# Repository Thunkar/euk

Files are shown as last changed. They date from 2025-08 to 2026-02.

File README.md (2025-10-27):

# EUK Split Keyboard

A split ergonomic keyboard project with customizable accessories and per-key RGB lighting.

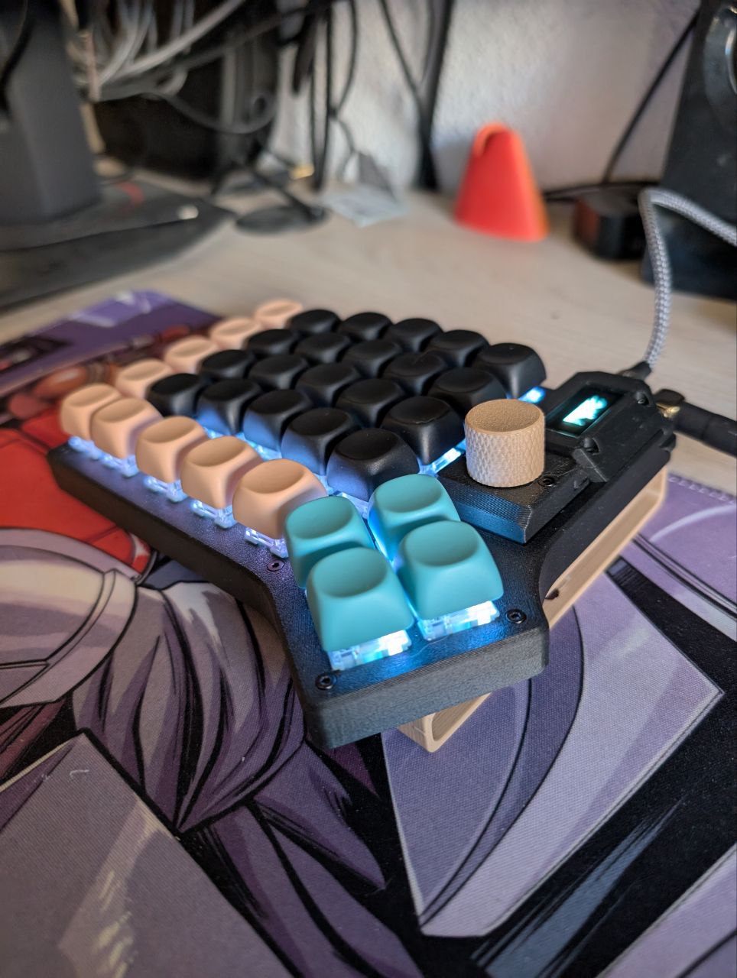
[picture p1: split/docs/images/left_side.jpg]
Left side

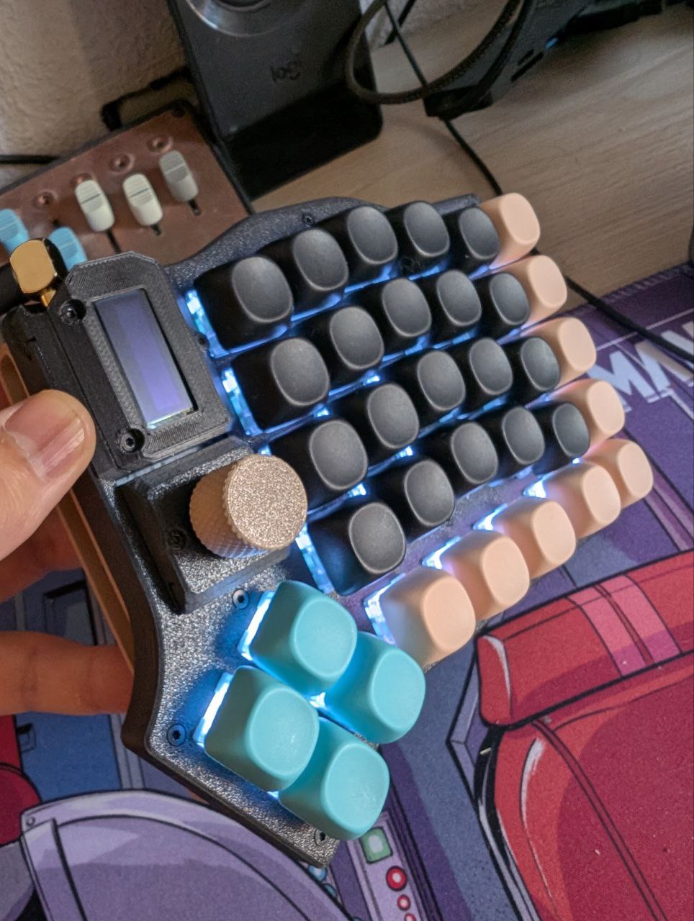
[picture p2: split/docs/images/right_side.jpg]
Right side

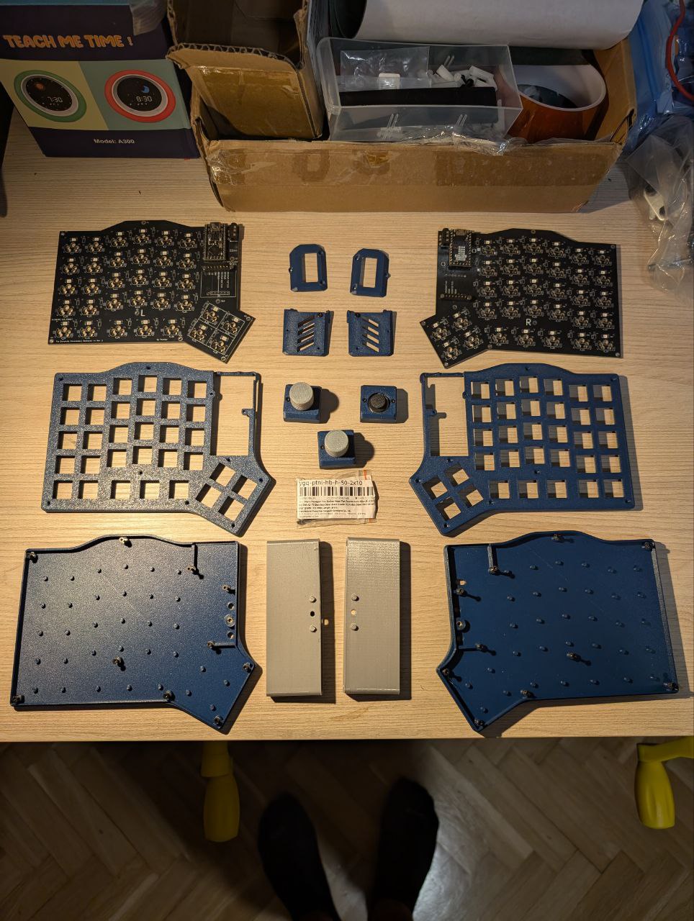
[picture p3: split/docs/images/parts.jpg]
Parts


## Features

- Split design for ergonomic typing
- Hot-swappable MX switches
- Per-key RGB lighting (SK6812 mini-e LEDs)
- RP2040-based controller
- Optional accessories:
  - OLED screen
  - Rotary encoder
  - Analog joystick
  - Potentiometer
  - Tenting support

## Documentation

- [Bill of Materials (BOM)](./split/docs/BOM.md) - Complete list of components needed
- [Ordering PCBs](./split/docs/ORDERING_PCBS.md) - Guide for ordering the printed circuit boards
- [Assembly Guide](./split/docs/ASSEMBLY.md) - Step-by-step assembly instructions

## Project Structure

- `cad/` - 3D printable case and accessory files
- `pcb/` - KiCad PCB design files
- `docs/` - Documentation and guides
- `via.layout.json` - VIA keyboard configurator layout
- `via.definition.json` - VIA keyboard definition
- `kle.definition.json` - https://keyboard-layout-editor.com/ definition

## Getting Started

1. Review the [BOM](docs/BOM.md) to buy all required components
2. Follow the [PCB ordering guide](docs/ORDERING_PCBS.md) and get yourself some boards
3. Print the required parts from the `cad/` directory
4. Follow the [assembly guide](docs/ASSEMBLY.md) to build it!

## Firmware

This keyboard uses QMK/VIA firmware. Use the included `via.layout.json` file to configure your keyboard layout in [VIA](https://usevia.app/).

At the moment, use the QMK fork at https://github.com/Thunkar/qmk_firmware

After installation, flash with:

`qmk flash -kb euk/split -km default`

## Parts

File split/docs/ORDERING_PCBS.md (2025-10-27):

# JLCPCB

To keep manufacturing costs low, there's actually a single PCB in this project. Flip it around, you have the other hand! It follows that you at least need 2 PCBs to to assemble a single keyboard.

This project was created around JLCPCB's PCB assembly service. In the end, no SMD components are assembled from the factory, so any other PCB manufacturing service will do.

To order, just upload the production files under `pcb/jlcpcb/production_files` (GERBER .zip and BOM/CPL files). Keep ALL options in their default settings, except for the PCB color which can be selected according to taste (or lack thereof).

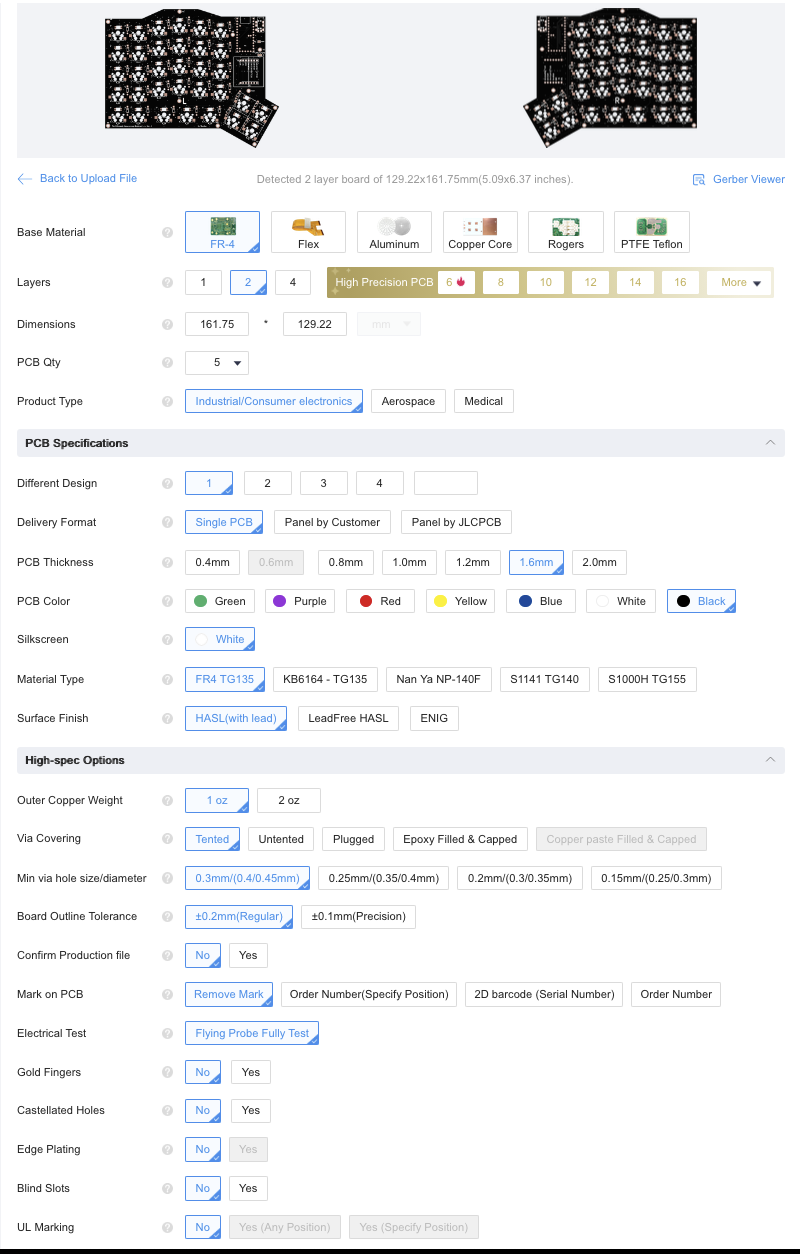
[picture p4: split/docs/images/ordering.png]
default settings


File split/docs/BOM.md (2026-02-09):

# BOM

## Hardware (per side)

| Item | Quantity | Link |
| --- | --- | --- |
| M2x10mm countersunk screw | 8 | https://es.aliexpress.com/item/1005006468976904.html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 |
| M2x14mm countersunk screw | 2 | https://es.aliexpress.com/item/1005006468976904.html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 |
| M2x4mm countersunk screw | 1 | https://es.aliexpress.com/item/1005006468976904.html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 |
| M3x6mm countersunk screw | 1 | https://es.aliexpress.com/item/1005006468976904.html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 |
| M2x4x3.2mm brass inserts | 10 | https://es.aliexpress.com/item/1005006472702418.html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 |
| M2x3x3.2mm brass inserts | 1 | https://es.aliexpress.com/item/1005006472702418.html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 |
| M3x6x4.5mm brass inserts | 1 | https://es.aliexpress.com/item/1005006472702418.html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 |
| TRRS jack female | 1 | https://es.aliexpress.com/item/33029465106.html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 |
| RP2040 pro micro | 1 | https://es.aliexpress.com/item/1005006599393967.html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 |
| 7 pin POGO connectors | 1 pair | https://es.aliexpress.com/item/1005005284441979.html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 |
| Hot swappable MX sockets (1511) | 33 | https://es.aliexpress.com/item/1005007639688349.html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,scm-url:1007.40050.354490.0,pvid:6b06f592-2422-491c-a082-58f7d255a081,tpp_buckets:668%232846%238115%232000&pdp_ext_f=%7B%22order%22%3A%2225%22%2C%22eval%22%3A%221%22%2C%22sceneId%22%3A%2230050%22%2C%22fromPage%22%3A%22recommend%22%7D&pdp_npi=6%40dis%21EUR%213.43%213.09%21%21%2127.71%2124.96%21%40211b80c217614877862336159e153c%2112000041605806626%21rec%21ES%21137979760%21XZ%211%210%21n_tag%3A-29919%3Bd%3A60ba6b69%3Bm03_new_user%3A-29895&utparam-url=scene%3ApcDetailBottomMoreOtherSeller%7Cquery_from%3A%7Cx_object_id%3A1005007639688349%7C_p_origin_prod%3A |
| SK6812 mini-e LEDs | 33 | https://es.aliexpress.com/item/1005007863635868.html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 |
| 1N4148 DO-35 diode | 33 | https://es.aliexpress.com/item/1005009372401863.html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 |
| OLED screen | 1 | https://es.aliexpress.com/item/1005008640132638.html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 |

## Misc hardware

| Item | Quantity | Link |
| --- | --- | --- |
| TRRS cable | 1 | https://es.aliexpress.com/item/1005005658637420.html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 |

## Optional

| Item | Quantity | Link |
| --- | --- | --- |
| EC11 encoder (short stem) | 1 | https://es.aliexpress.com/item/1005003569104746.html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,scm-url:1007.40050.354490.0,pvid:5a6a783c-6c5c-47c6-a442-9901f6537dc1,tpp_buckets:668%232846%238115%232000&pdp_ext_f=%7B%22order%22%3A%228%22%2C%22eval%22%3A%221%22%2C%22sceneId%22%3A%2230050%22%2C%22fromPage%22%3A%22recommend%22%7D&pdp_npi=6%40dis%21EUR%210.76%210.63%21%21%210.86%210.71%21%40211b6c1917614890539918085e8606%2112000051081200717%21rec%21ES%21137979760%21XZ%211%210%21n_tag%3A-29919%3Bd%3A60ba6b69%3Bm03_new_user%3A-29895&utparam-url=scene%3ApcDetailTopMoreOtherSeller%7Cquery_from%3A%7Cx_object_id%3A1005003569104746%7C_p_origin_prod%3A |
| Joystick | 1 | https://es.aliexpress.com/item/1005006734905352.html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 |
| RK097N potentiometer | 1 | https://www.aliexpress.com/item/1005009223196391.html?spm=a2g0o.order_list.order_list_main.177.404c194dESBhOC |

# Printed parts

## Per side

| Part | Quantity |
|---|---|
| splitBase.stl | 1 |
| splitTop.stl | 1 |
| mcuCover.stl | 1 |
| screenHolder.stl | 1 |

## Accessories

### Tenting

| Part | Quantity |
|---|---|
| tent.stl | 1 |

### Encoder

| Part | Quantity |
|---|---|
| encoderEnclosureBase.stl | 1 |
| encoderEnclosureMid.stl | 1 |
| encoderEnclosureTop.stl | 1 |
| pad.stl | 1 |

### Potentiometer

| Part | Quantity |
|---|---|
| potEnclosureBase.stl | 1 |
| potEnclosureMid.stl | 1 |
| potEnclosureTop.stl | 1 |
| pad.stl | 1 |

### Joystick

| Part | Quantity |
|---|---|
| joytstickEnclosureBase.stl | 1 |
| joytstickEnclosureMid.stl | 1 |
| joytstickEnclosureTop.stl | 1 |
| pad.stl | 1 |

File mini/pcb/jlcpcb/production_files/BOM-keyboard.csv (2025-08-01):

Comment | Designator | Footprint | LCSC | Quantity
D | D_0,D_1,D_10,D_11,D_12,D_13,D_14,D_15,D_16,D_17,D_18,D_19,D_2,D_20,D_21,D_22,D_23,D_24,D_25,D_26,D_27,D_28,D_29,D_3,D_30,D_31,D_32,D_4,D_5,D_6,D_7,D_8,D_9 | D_SOD-123_Reversible | C8598 | 33
KEYSW | K_5 | Kailh_socket_MX_reversible |  | 1
KEYSW | K_1 | Kailh_socket_MX_reversible |  | 1
KEYSW | K_4 | Kailh_socket_MX_reversible |  | 1
KEYSW | K_32 | Kailh_socket_MX_reversible |  | 1
KEYSW | K_31 | Kailh_socket_MX_reversible |  | 1
KEYSW | K_30 | Kailh_socket_MX_reversible |  | 1
KEYSW | K_29 | Kailh_socket_MX_reversible |  | 1
KEYSW | K_28 | Kailh_socket_MX_reversible |  | 1
KEYSW | K_27 | Kailh_socket_MX_reversible |  | 1
KEYSW | K_26 | Kailh_socket_MX_reversible |  | 1
KEYSW | K_25 | Kailh_socket_MX_reversible |  | 1
KEYSW | K_24 | Kailh_socket_MX_reversible |  | 1
KEYSW | K_23 | Kailh_socket_MX_reversible |  | 1
KEYSW | K_22 | Kailh_socket_MX_reversible |  | 1
KEYSW | K_21 | Kailh_socket_MX_reversible |  | 1
KEYSW | K_20 | Kailh_socket_MX_reversible |  | 1
KEYSW | K_19 | Kailh_socket_MX_reversible |  | 1
KEYSW | K_18 | Kailh_socket_MX_reversible |  | 1
KEYSW | K_17 | Kailh_socket_MX_reversible |  | 1
KEYSW | K_16 | Kailh_socket_MX_reversible |  | 1
KEYSW | K_15 | Kailh_socket_MX_reversible |  | 1
KEYSW | K_14 | Kailh_socket_MX_reversible |  | 1
KEYSW | K_13 | Kailh_socket_MX_reversible |  | 1
KEYSW | K_12 | Kailh_socket_MX_reversible |  | 1
KEYSW | K_11 | Kailh_socket_MX_reversible |  | 1
KEYSW | K_10 | Kailh_socket_MX_reversible |  | 1
KEYSW | K_9 | Kailh_socket_MX_reversible |  | 1
KEYSW | K_8 | Kailh_socket_MX_reversible |  | 1
KEYSW | K_7 | Kailh_socket_MX_reversible |  | 1
KEYSW | K_6 | Kailh_socket_MX_reversible |  | 1
KEYSW | K_3 | Kailh_socket_MX_reversible |  | 1
KEYSW | K_2 | Kailh_socket_MX_reversible |  | 1
KEYSW | K_0 | Kailh_socket_MX_reversible |  | 1
IO | J2 | PinHeader_1x05_P2.54mm_Vertical |  | 1
TRRS | J1 | TRRS_JACK_MJ4PP9 |  | 1
WS2812B | D25 | SK6812-MINI-E |  | 1
WS2812B | D2 | SK6812-MINI-E |  | 1
WS2812B | D27 | SK6812-MINI-E |  | 1
WS2812B | D33 | SK6812-MINI-E |  | 1
WS2812B | D28 | SK6812-MINI-E |  | 1
WS2812B | D32 | SK6812-MINI-E |  | 1
WS2812B | D31 | SK6812-MINI-E |  | 1
WS2812B | D3 | SK6812-MINI-E |  | 1
WS2812B | D12 | SK6812-MINI-E |  | 1
WS2812B | D15 | SK6812-MINI-E |  | 1
WS2812B | D1 | SK6812-MINI-E |  | 1
WS2812B | D16 | SK6812-MINI-E |  | 1
WS2812B | D18 | SK6812-MINI-E |  | 1
WS2812B | D29 | SK6812-MINI-E |  | 1
WS2812B | D13 | SK6812-MINI-E |  | 1
WS2812B | D6 | SK6812-MINI-E |  | 1
WS2812B | D21 | SK6812-MINI-E |  | 1
WS2812B | D4 | SK6812-MINI-E |  | 1
WS2812B | D26 | SK6812-MINI-E |  | 1
WS2812B | D20 | SK6812-MINI-E |  | 1
WS2812B | D17 | SK6812-MINI-E |  | 1
WS2812B | D5 | SK6812-MINI-E |  | 1
WS2812B | D11 | SK6812-MINI-E |  | 1
WS2812B | D30 | SK6812-MINI-E |  | 1
WS2812B | D8 | SK6812-MINI-E |  | 1
WS2812B | D7 | SK6812-MINI-E |  | 1
WS2812B | D10 | SK6812-MINI-E |  | 1
WS2812B | D22 | SK6812-MINI-E |  | 1
WS2812B | D14 | SK6812-MINI-E |  | 1
WS2812B | D9 | SK6812-MINI-E |  | 1
WS2812B | D24 | SK6812-MINI-E |  | 1
WS2812B | D19 | SK6812-MINI-E |  | 1
WS2812B | D23 | SK6812-MINI-E |  | 1
~ | U1 | pro_micro_rp2040 |  | 1

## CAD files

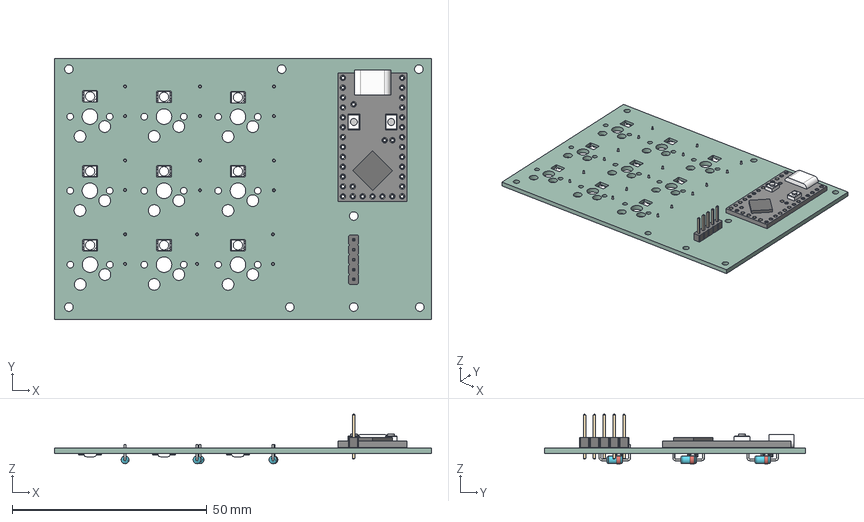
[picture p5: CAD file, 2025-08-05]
mini/pcb/keyboard-mini.step
96.9 x 67.1 x 12.7 mm
Pins x 9
PinHeader_1x05_P2.54mm_Vertical
pro_micro_rp2040
D_DO-35_SOD27_P7.62mm_Horizontal x 9
keyboard-mini_PCB

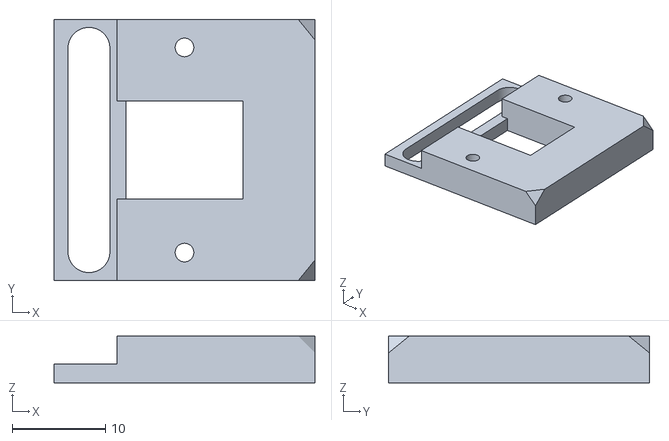
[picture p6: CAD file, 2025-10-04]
split/cad/potEnclosureMid.stl
28.0 x 28.0 x 5.00

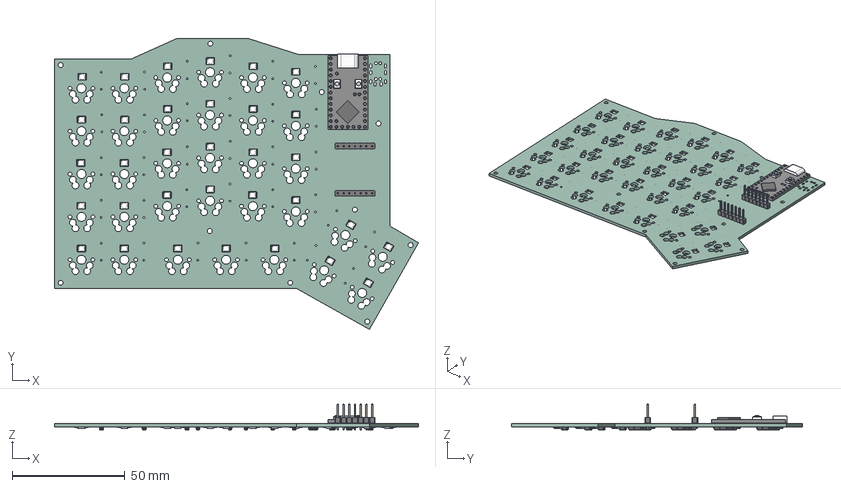
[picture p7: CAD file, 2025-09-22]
split/pcb/rev2.step
161.8 x 129.2 x 11.5 mm
PinHeader_1x07_P2.54mm_Vertical x 2
pro_micro_rp2040
D_SOD-123 x 33
Pins x 33
keyboard_PCB

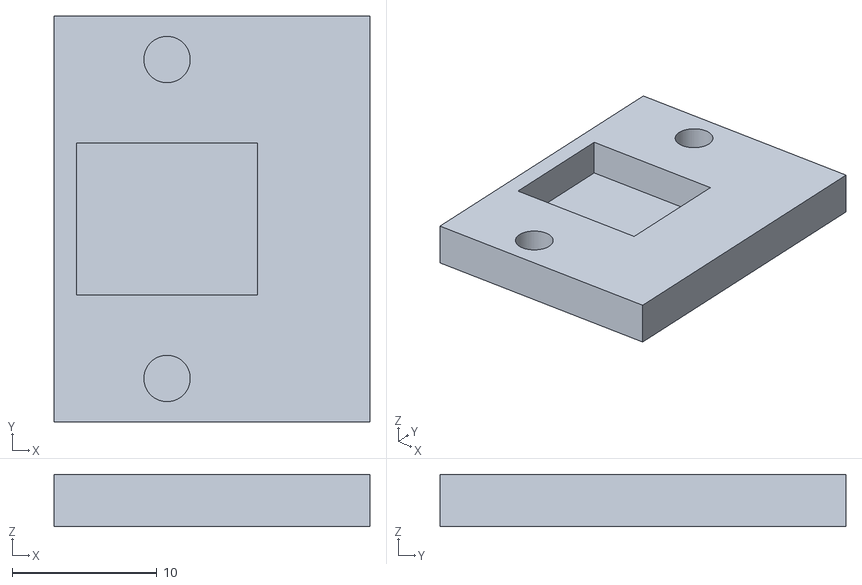
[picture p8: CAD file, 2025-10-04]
split/cad/potEnclosureBase.stl
21.8 x 28.0 x 3.60

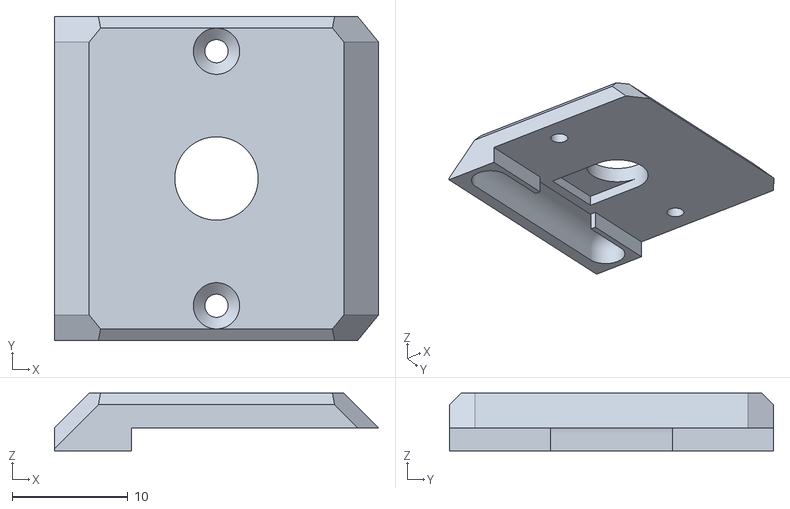
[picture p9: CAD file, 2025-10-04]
split/cad/potEnclosureTop.stl
28.0 x 28.0 x 5.00

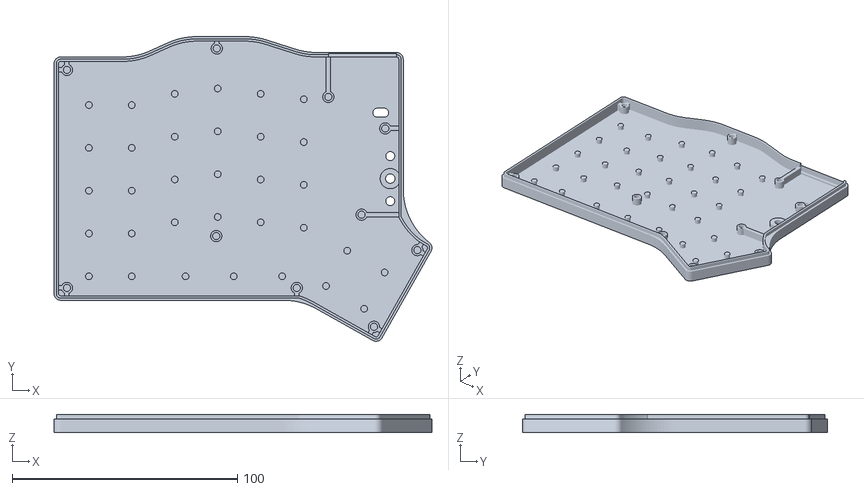
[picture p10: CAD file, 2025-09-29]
split/cad/splitBase.stl
167.7 x 135.2 x 8.00

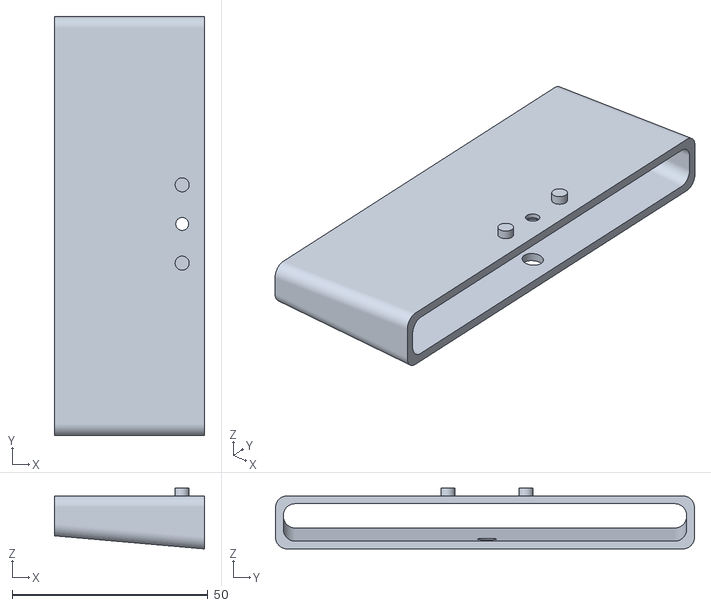
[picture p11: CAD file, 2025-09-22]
split/cad/tent.stl
38.4 x 107.0 x 15.6

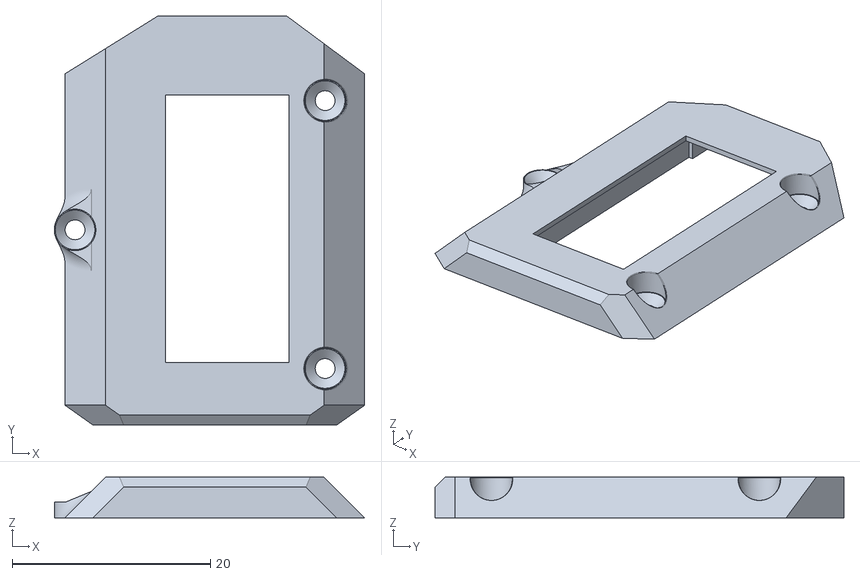
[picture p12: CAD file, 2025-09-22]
split/cad/screenHolder.stl
31.4 x 41.3 x 4.10

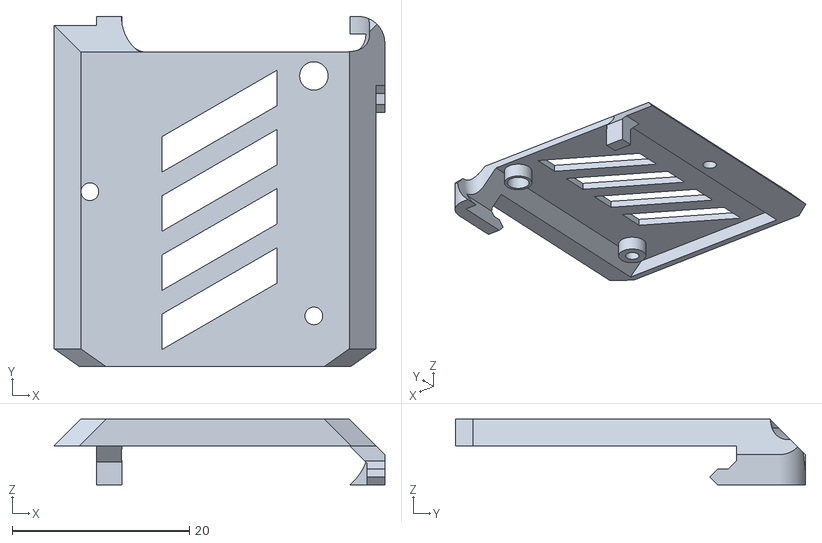
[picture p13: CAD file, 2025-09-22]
split/cad/mcuCover.stl
37.3 x 39.5 x 7.40

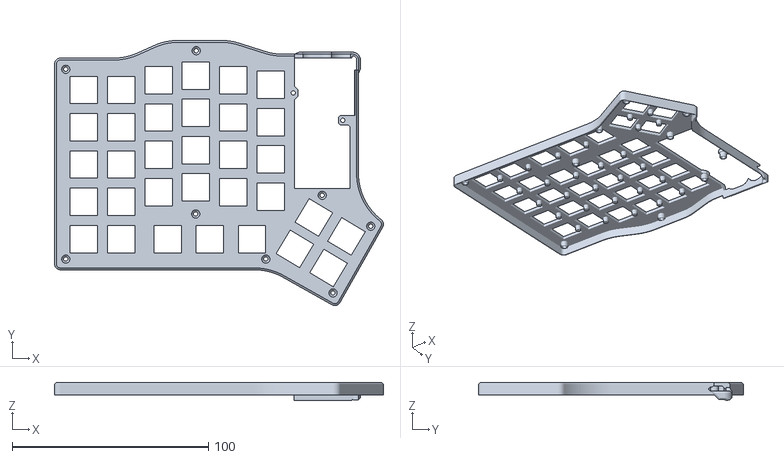
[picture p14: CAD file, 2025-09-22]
split/cad/splitTop.stl
167.7 x 135.2 x 9.40

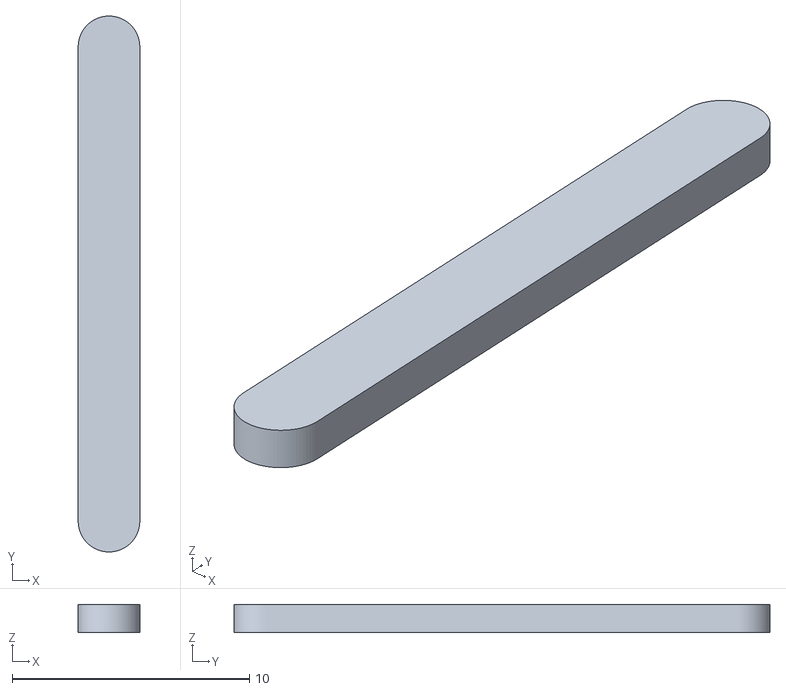
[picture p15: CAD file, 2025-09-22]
split/cad/pad.stl
2.60 x 22.6 x 1.20

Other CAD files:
split/cad/encoderEnclosureMid.stl
split/cad/encoderEnclosureBase.stl
split/cad/encoderEnclosureTop.stl

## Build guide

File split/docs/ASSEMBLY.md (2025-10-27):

# Soldering

Pay close attention to the orientation of components and which side of the PCB you're actually assembling. Most of the soldering for a given side must be done from the OPPOSITE SIDE. Once assembled, everything except for the MCU, TRRS jack and magnetic connector will be the bottom of the board.

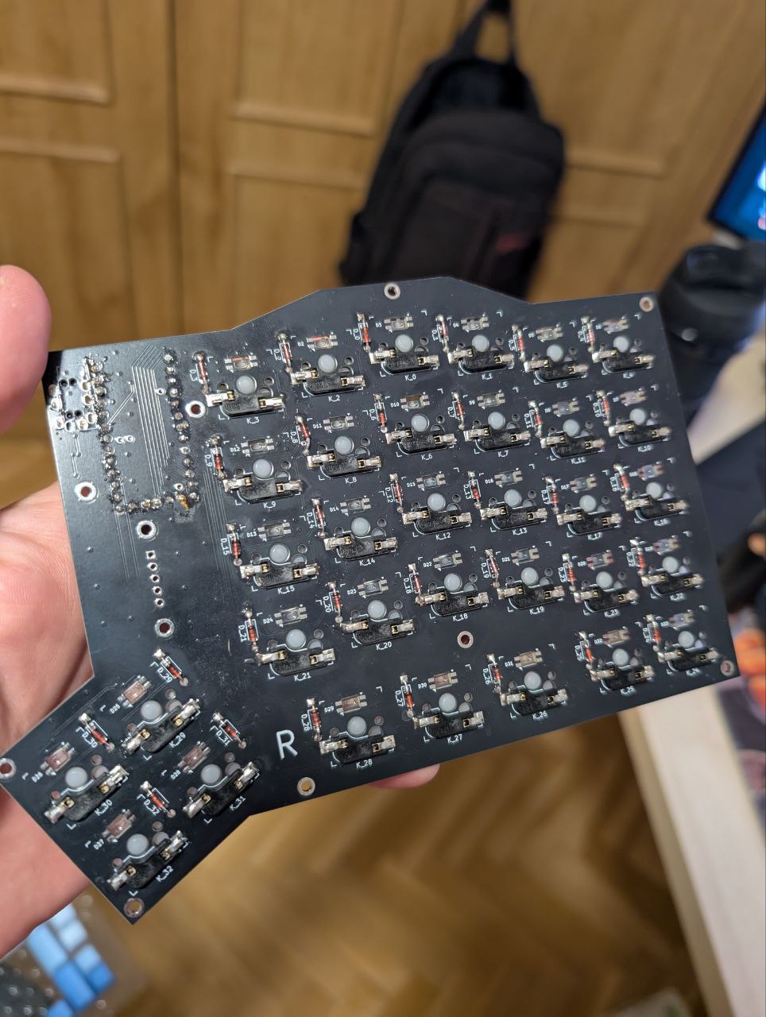
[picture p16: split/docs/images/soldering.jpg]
soldering


## LEDs

Painful to do by hand (not an oven) and with a soldering iron, but doable. LEDs are EXTREMELY EASY TO DAMAGE, so try to be gentle with the tool. The cut corner on the LED should be placed on the lower left corner.

## MCU

Do not use sockets, or the case will not fit. Solder the MCU directly using pin headers!
For the right hand, the MCU board should be soldered UPSIDE DOWN. There's an extra pin header needed for the boot pin, which will be exposed on the bottom of the board (the case has a hole for easy access).

After soldering the LEDs and the MCU, the test script under `sw/test` on this repo can be used to verify they work (it will display a rainbow effect)

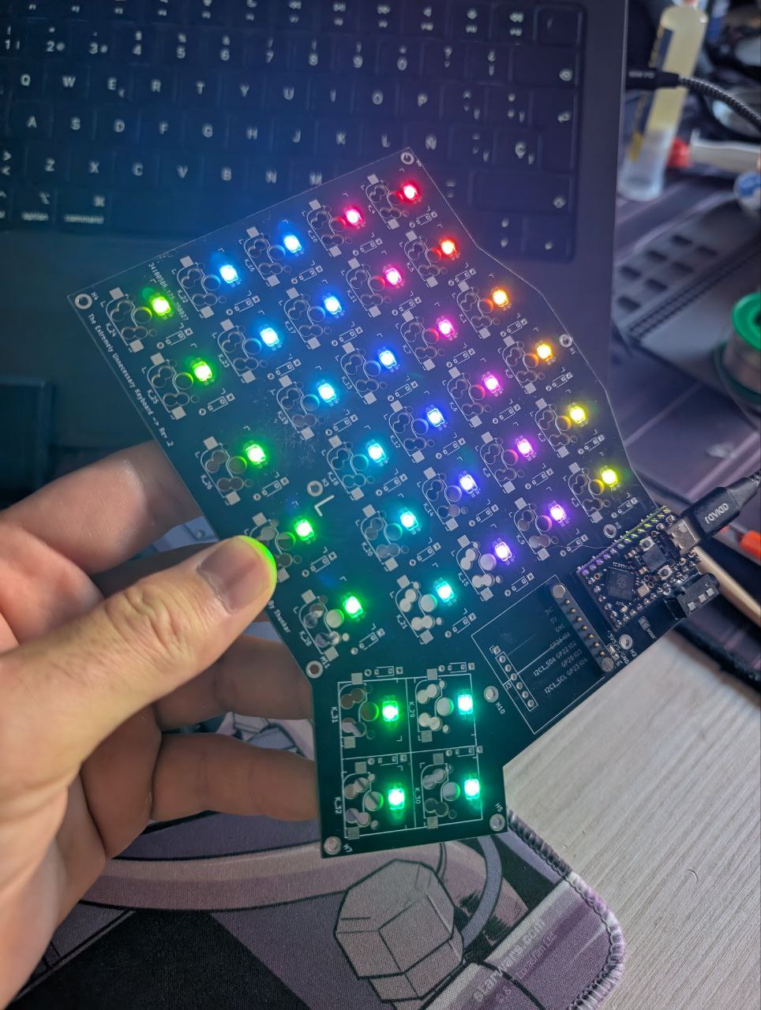
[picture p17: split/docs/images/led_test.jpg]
led_test


## OLED screens

Must be soldered directly to the MCU pins (5V, GND, GPIO25/SCL, GPIO16/SDA).

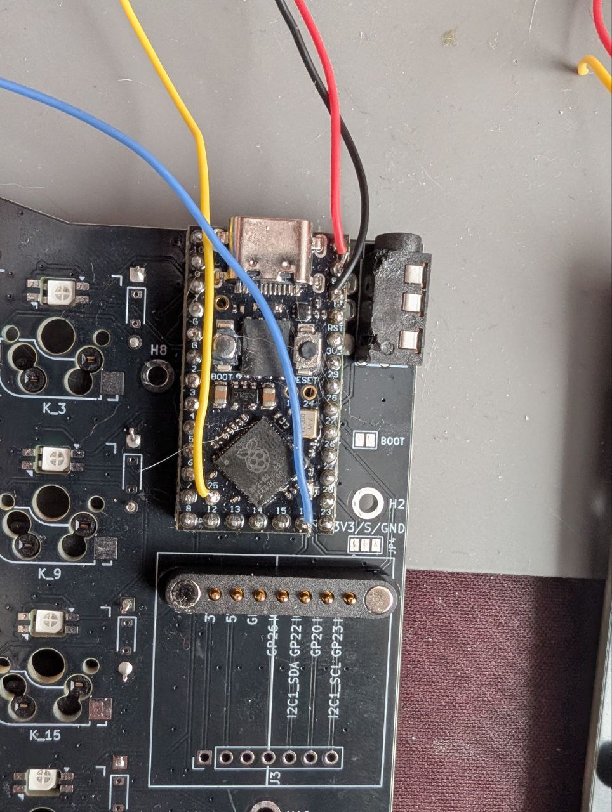
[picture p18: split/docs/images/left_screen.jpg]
left_screen

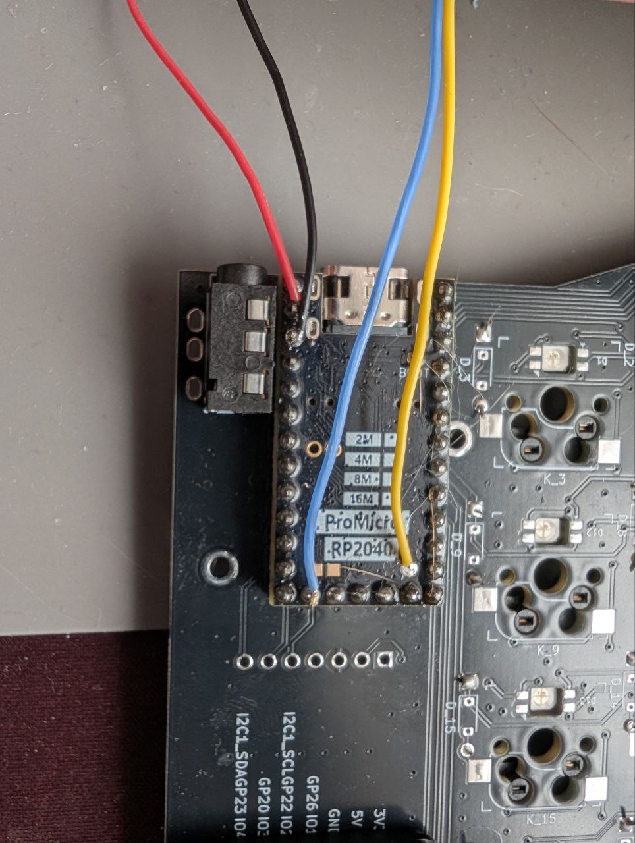
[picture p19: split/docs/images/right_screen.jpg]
right_screen


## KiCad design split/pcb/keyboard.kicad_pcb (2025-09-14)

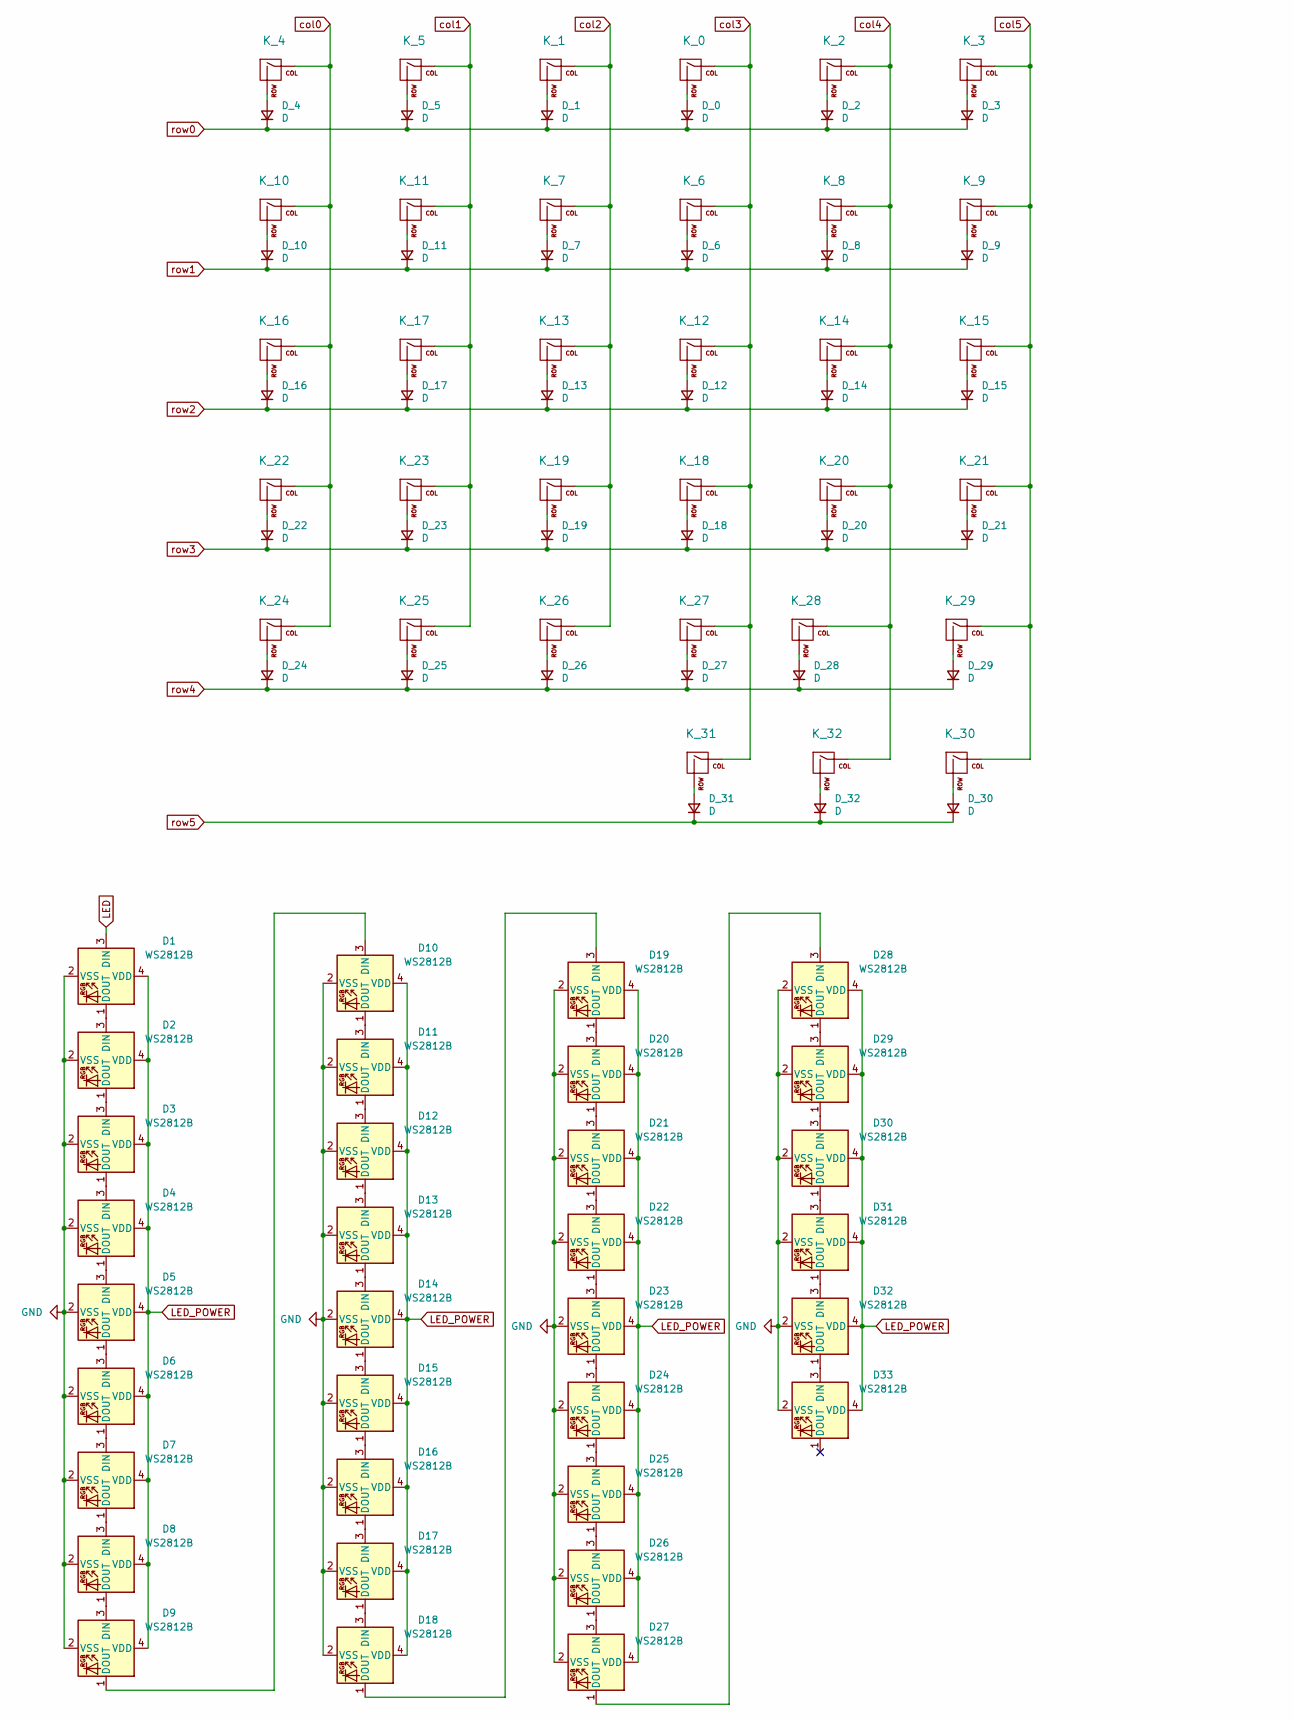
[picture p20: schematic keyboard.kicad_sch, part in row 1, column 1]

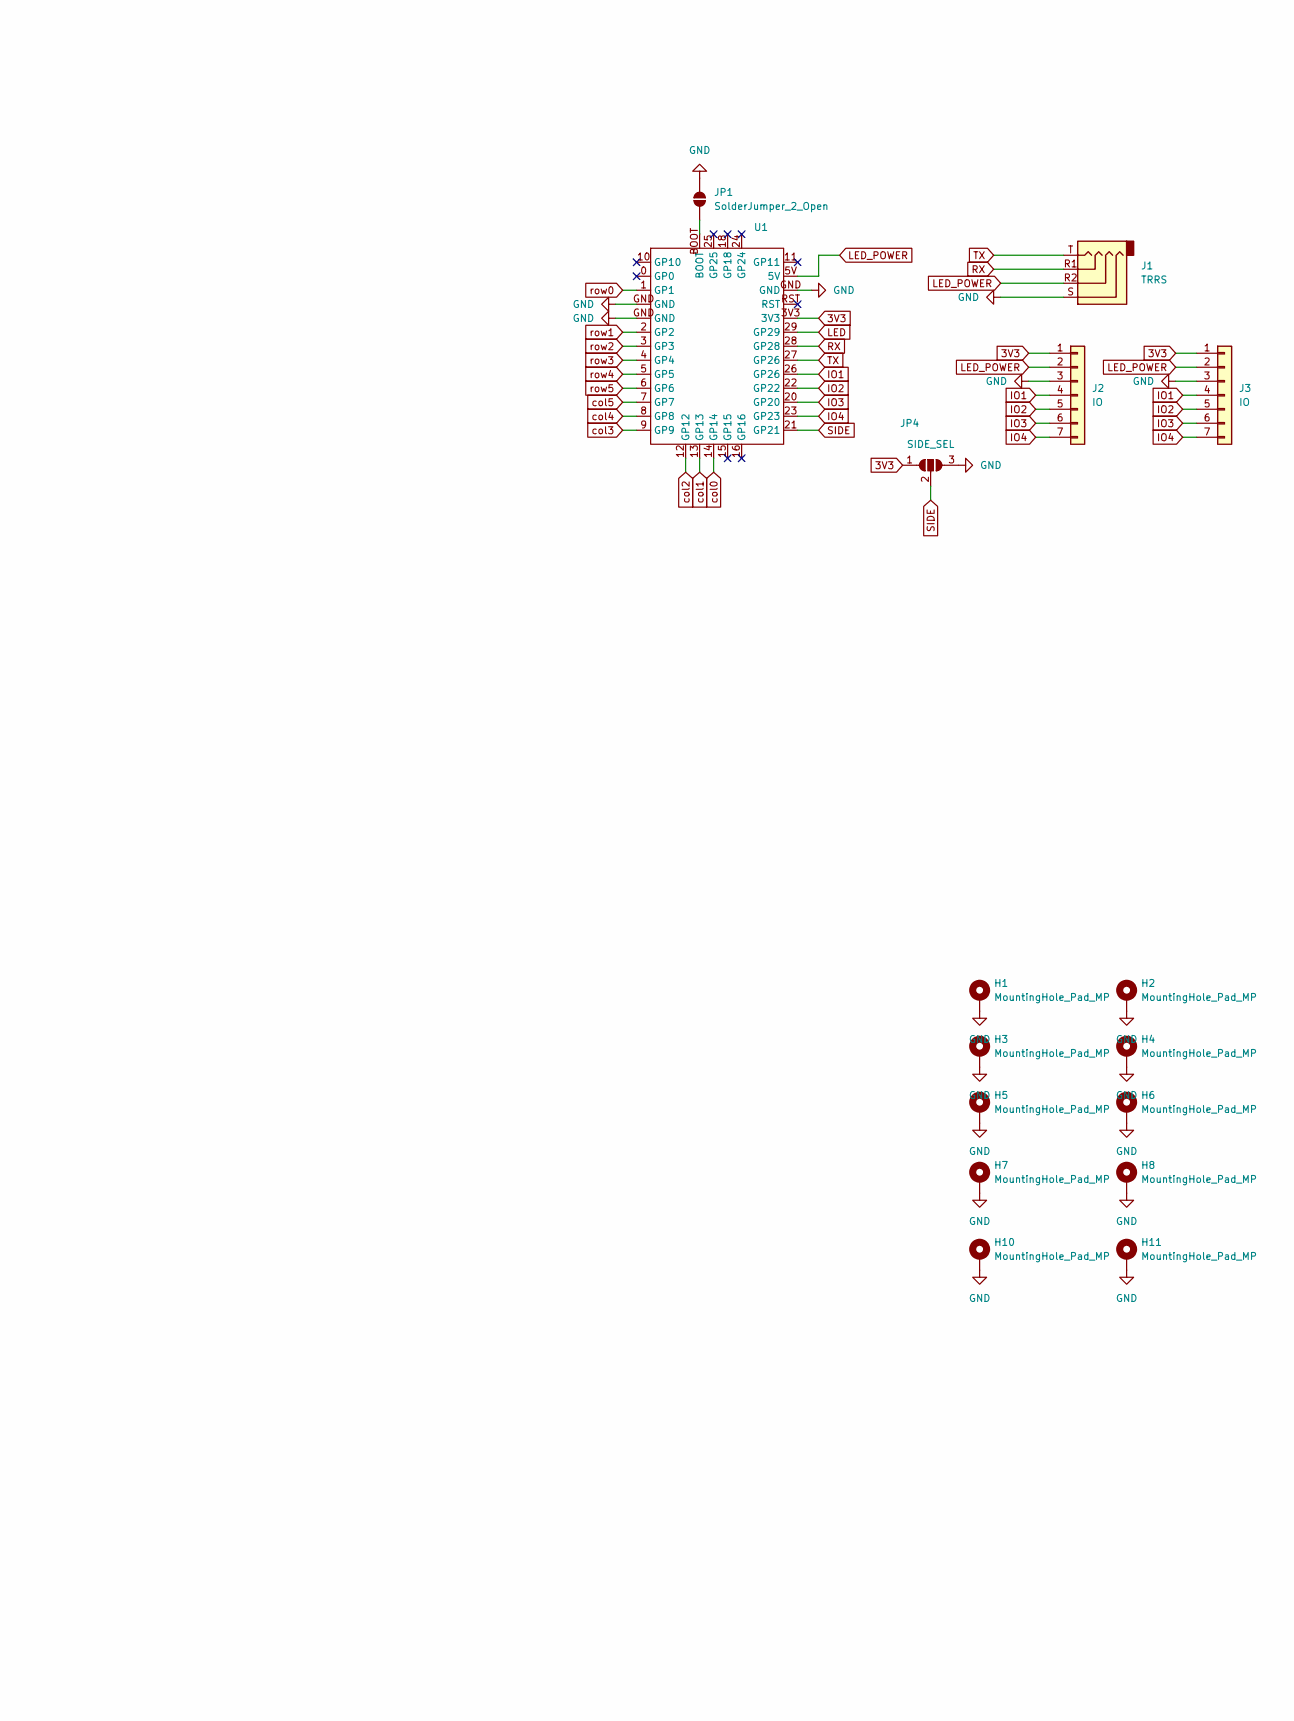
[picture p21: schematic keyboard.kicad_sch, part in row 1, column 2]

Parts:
D1, D2, D3, D4, D5, D6, D7, D8, D9, D10, D11, D12, D13, D14, D15, D16, D17, D18, D19, D20, D21, D22, D23, D24, D25, D26, D27, D28, D29, D30, D31, D32, D33: WS2812B; SK6812-MINI-E
D_0, D_1, D_2, D_3, D_4, D_5, D_6, D_7, D_8, D_9, D_10, D_11, D_12, D_13, D_14, D_15, D_16, D_17, D_18, D_19, D_20, D_21, D_22, D_23, D_24, D_25, D_26, D_27, D_28, D_29, D_30, D_31, D_32: D; D_SOD-123_Reversible
H1, H2, H3, H4, H5, H6, H7, H8, H10, H11: MountingHole_Pad_MP; MountingHole_2.2mm_M2_DIN965_Pad
J1: TRRS; TRRS_JACK_MJ4PP9
J2, J3: IO; PinHeader_1x07_P2.54mm_Vertical
JP1: SolderJumper_2_Open; SolderJumper-2_P1.3mm_Open_Pad1.0x1.5mm
JP4: SIDE_SEL; SolderJumper-3_P1.3mm_Open_Pad1.0x1.5mm
K_0, K_1, K_2, K_3, K_4, K_5, K_6, K_7, K_8, K_9, K_10, K_11, K_12, K_13, K_14, K_15, K_16, K_17, K_18, K_19, K_20, K_21, K_22, K_23, K_24, K_25, K_26, K_27, K_28, K_29, K_30, K_31, K_32: KEYSW; Kailh_socket_MX_reversible
U1: pro_micro_rp2040

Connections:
3V3: J2.1, J3.1, JP4.1 (A), U1.3V3
GND: D1.2 (VSS), D2.2 (VSS), D3.2 (VSS), D4.2 (VSS), D5.2 (VSS), D6.2 (VSS), D7.2 (VSS), D8.2 (VSS), D9.2 (VSS), D10.2 (VSS), D11.2 (VSS), D12.2 (VSS), D13.2 (VSS), D14.2 (VSS), D15.2 (VSS), D16.2 (VSS), D17.2 (VSS), D18.2 (VSS), D19.2 (VSS), D20.2 (VSS), D21.2 (VSS), D22.2 (VSS), D23.2 (VSS), D24.2 (VSS), D25.2 (VSS), D26.2 (VSS), D27.2 (VSS), D28.2 (VSS), D29.2 (VSS), D30.2 (VSS), D31.2 (VSS), D32.2 (VSS), D33.2 (VSS), H1.1, H2.1, H3.1, H4.1, H5.1, H6.1, H7.1, H8.1, H10.1, H11.1, J1.S, J2.3, J3.3, JP1.2 (B), JP4.3 (B), U1.GND
IO1: J2.4, J3.4, U1.26 (GP26)
IO2: J2.5, J3.5, U1.22 (GP22)
IO3: J2.6, J3.6, U1.20 (GP20)
IO4: J2.7, J3.7, U1.23 (GP23)
LED: D1.3 (DIN), U1.29 (GP29)
LED_POWER: D1.4 (VDD), D2.4 (VDD), D3.4 (VDD), D4.4 (VDD), D5.4 (VDD), D6.4 (VDD), D7.4 (VDD), D8.4 (VDD), D9.4 (VDD), D10.4 (VDD), D11.4 (VDD), D12.4 (VDD), D13.4 (VDD), D14.4 (VDD), D15.4 (VDD), D16.4 (VDD), D17.4 (VDD), D18.4 (VDD), D19.4 (VDD), D20.4 (VDD), D21.4 (VDD), D22.4 (VDD), D23.4 (VDD), D24.4 (VDD), D25.4 (VDD), D26.4 (VDD), D27.4 (VDD), D28.4 (VDD), D29.4 (VDD), D30.4 (VDD), D31.4 (VDD), D32.4 (VDD), D33.4 (VDD), J1.R2, J2.2, J3.2, U1.5V
unnamed: D1.1 (DOUT), D2.3 (DIN)
unnamed: D2.1 (DOUT), D3.3 (DIN)
unnamed: D3.1 (DOUT), D4.3 (DIN)
unnamed: D4.1 (DOUT), D5.3 (DIN)
unnamed: D5.1 (DOUT), D6.3 (DIN)
unnamed: D6.1 (DOUT), D7.3 (DIN)
unnamed: D7.1 (DOUT), D8.3 (DIN)
unnamed: D8.1 (DOUT), D9.3 (DIN)
unnamed: D9.1 (DOUT), D10.3 (DIN)
unnamed: D10.1 (DOUT), D11.3 (DIN)
unnamed: D11.1 (DOUT), D12.3 (DIN)
unnamed: D12.1 (DOUT), D13.3 (DIN)
unnamed: D13.1 (DOUT), D14.3 (DIN)
unnamed: D14.1 (DOUT), D15.3 (DIN)
unnamed: D15.1 (DOUT), D16.3 (DIN)
unnamed: D16.1 (DOUT), D17.3 (DIN)
unnamed: D17.1 (DOUT), D18.3 (DIN)
unnamed: D18.1 (DOUT), D19.3 (DIN)
unnamed: D19.1 (DOUT), D20.3 (DIN)
unnamed: D20.1 (DOUT), D21.3 (DIN)
unnamed: D21.1 (DOUT), D22.3 (DIN)
unnamed: D22.1 (DOUT), D23.3 (DIN)
unnamed: D23.1 (DOUT), D24.3 (DIN)
unnamed: D24.1 (DOUT), D25.3 (DIN)
unnamed: D25.1 (DOUT), D26.3 (DIN)
unnamed: D26.1 (DOUT), D27.3 (DIN)
unnamed: D27.1 (DOUT), D28.3 (DIN)
unnamed: D28.1 (DOUT), D29.3 (DIN)
unnamed: D29.1 (DOUT), D30.3 (DIN)
unnamed: D30.1 (DOUT), D31.3 (DIN)
unnamed: D31.1 (DOUT), D32.3 (DIN)
unnamed: D32.1 (DOUT), D33.3 (DIN)
unnamed: D_0.2 (A), K_0.2 (ROW)
unnamed: D_1.2 (A), K_1.2 (ROW)
unnamed: D_2.2 (A), K_2.2 (ROW)
unnamed: D_3.2 (A), K_3.2 (ROW)
unnamed: D_4.2 (A), K_4.2 (ROW)
unnamed: D_5.2 (A), K_5.2 (ROW)
unnamed: D_6.2 (A), K_6.2 (ROW)
unnamed: D_7.2 (A), K_7.2 (ROW)
unnamed: D_8.2 (A), K_8.2 (ROW)
unnamed: D_9.2 (A), K_9.2 (ROW)
unnamed: D_10.2 (A), K_10.2 (ROW)
unnamed: D_11.2 (A), K_11.2 (ROW)
unnamed: D_12.2 (A), K_12.2 (ROW)
unnamed: D_13.2 (A), K_13.2 (ROW)
unnamed: D_14.2 (A), K_14.2 (ROW)
unnamed: D_15.2 (A), K_15.2 (ROW)
unnamed: D_16.2 (A), K_16.2 (ROW)
unnamed: D_17.2 (A), K_17.2 (ROW)
unnamed: D_18.2 (A), K_18.2 (ROW)
unnamed: D_19.2 (A), K_19.2 (ROW)
unnamed: D_20.2 (A), K_20.2 (ROW)
unnamed: D_21.2 (A), K_21.2 (ROW)
unnamed: D_22.2 (A), K_22.2 (ROW)
unnamed: D_23.2 (A), K_23.2 (ROW)
unnamed: D_24.2 (A), K_24.2 (ROW)
unnamed: D_25.2 (A), K_25.2 (ROW)
unnamed: D_26.2 (A), K_26.2 (ROW)
unnamed: D_27.2 (A), K_27.2 (ROW)
unnamed: D_28.2 (A), K_28.2 (ROW)
unnamed: D_29.2 (A), K_29.2 (ROW)
unnamed: D_30.2 (A), K_30.2 (ROW)
unnamed: D_31.2 (A), K_31.2 (ROW)
unnamed: D_32.2 (A), K_32.2 (ROW)
unnamed: JP1.1 (A), U1.BOOT
RX: J1.R1, U1.28 (GP28)
SIDE: JP4.2 (C), U1.21 (GP21)
TX: J1.T, U1.27 (GP26)
col0: K_4.1 (COL), K_10.1 (COL), K_16.1 (COL), K_22.1 (COL), K_24.1 (COL), U1.14 (GP14)
col1: K_5.1 (COL), K_11.1 (COL), K_17.1 (COL), K_23.1 (COL), K_25.1 (COL), U1.13 (GP13)
col2: K_1.1 (COL), K_7.1 (COL), K_13.1 (COL), K_19.1 (COL), K_26.1 (COL), U1.12 (GP12)
col3: K_0.1 (COL), K_6.1 (COL), K_12.1 (COL), K_18.1 (COL), K_27.1 (COL), K_31.1 (COL), U1.9 (GP9)
col4: K_2.1 (COL), K_8.1 (COL), K_14.1 (COL), K_20.1 (COL), K_28.1 (COL), K_32.1 (COL), U1.8 (GP8)
col5: K_3.1 (COL), K_9.1 (COL), K_15.1 (COL), K_21.1 (COL), K_29.1 (COL), K_30.1 (COL), U1.7 (GP7)
row0: D_0.1 (K), D_1.1 (K), D_2.1 (K), D_3.1 (K), D_4.1 (K), D_5.1 (K), U1.1 (GP1)
row1: D_6.1 (K), D_7.1 (K), D_8.1 (K), D_9.1 (K), D_10.1 (K), D_11.1 (K), U1.2 (GP2)
row2: D_12.1 (K), D_13.1 (K), D_14.1 (K), D_15.1 (K), D_16.1 (K), D_17.1 (K), U1.3 (GP3)
row3: D_18.1 (K), D_19.1 (K), D_20.1 (K), D_21.1 (K), D_22.1 (K), D_23.1 (K), U1.4 (GP4)
row4: D_24.1 (K), D_25.1 (K), D_26.1 (K), D_27.1 (K), D_28.1 (K), D_29.1 (K), U1.5 (GP5)
row5: D_30.1 (K), D_31.1 (K), D_32.1 (K), U1.6 (GP6)

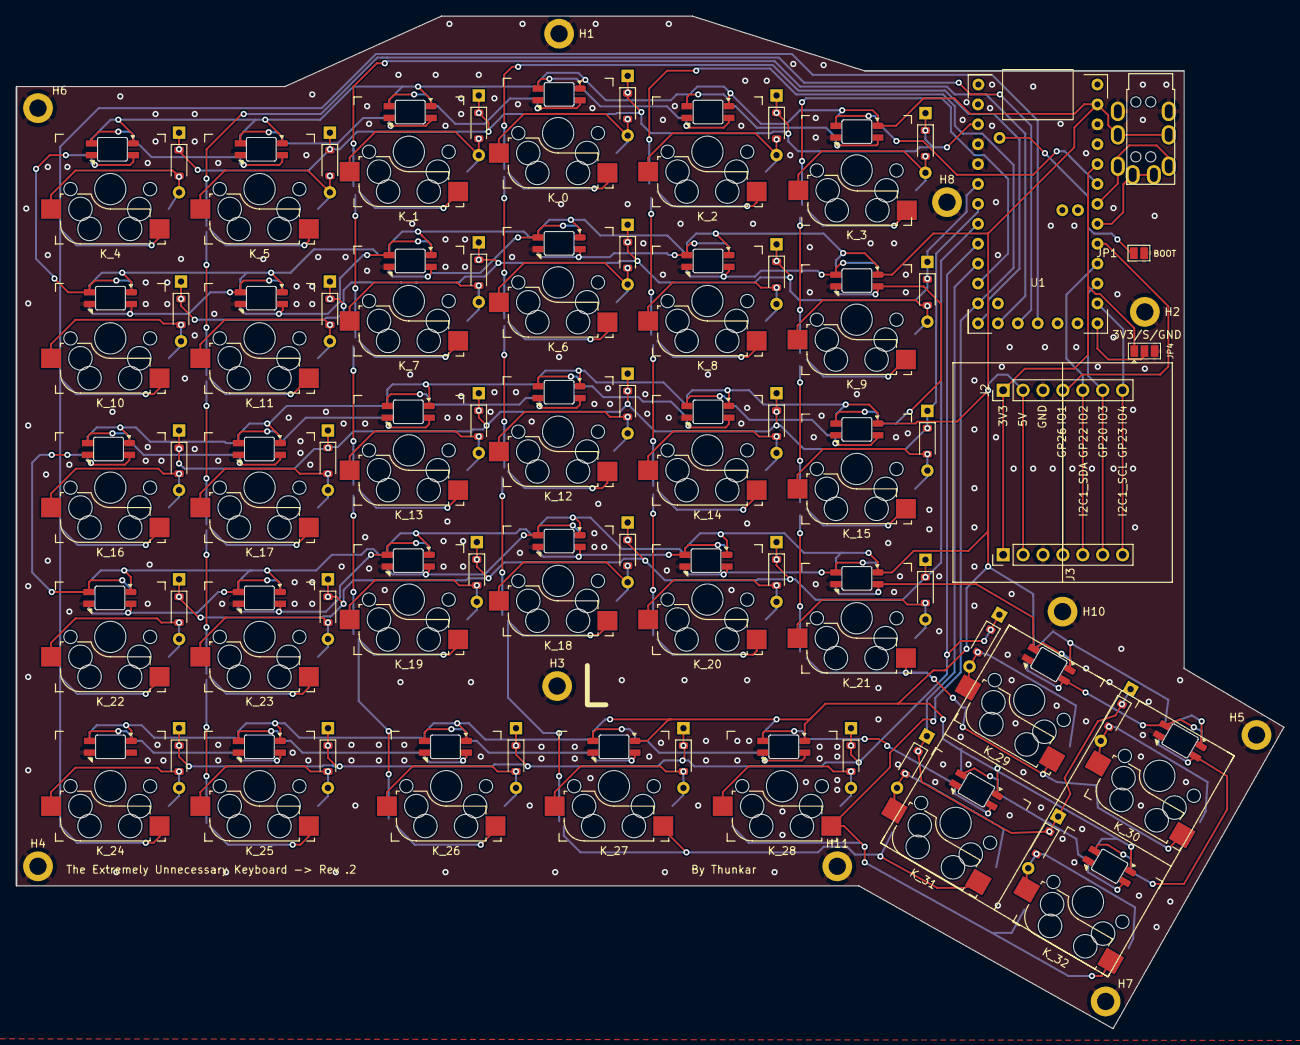
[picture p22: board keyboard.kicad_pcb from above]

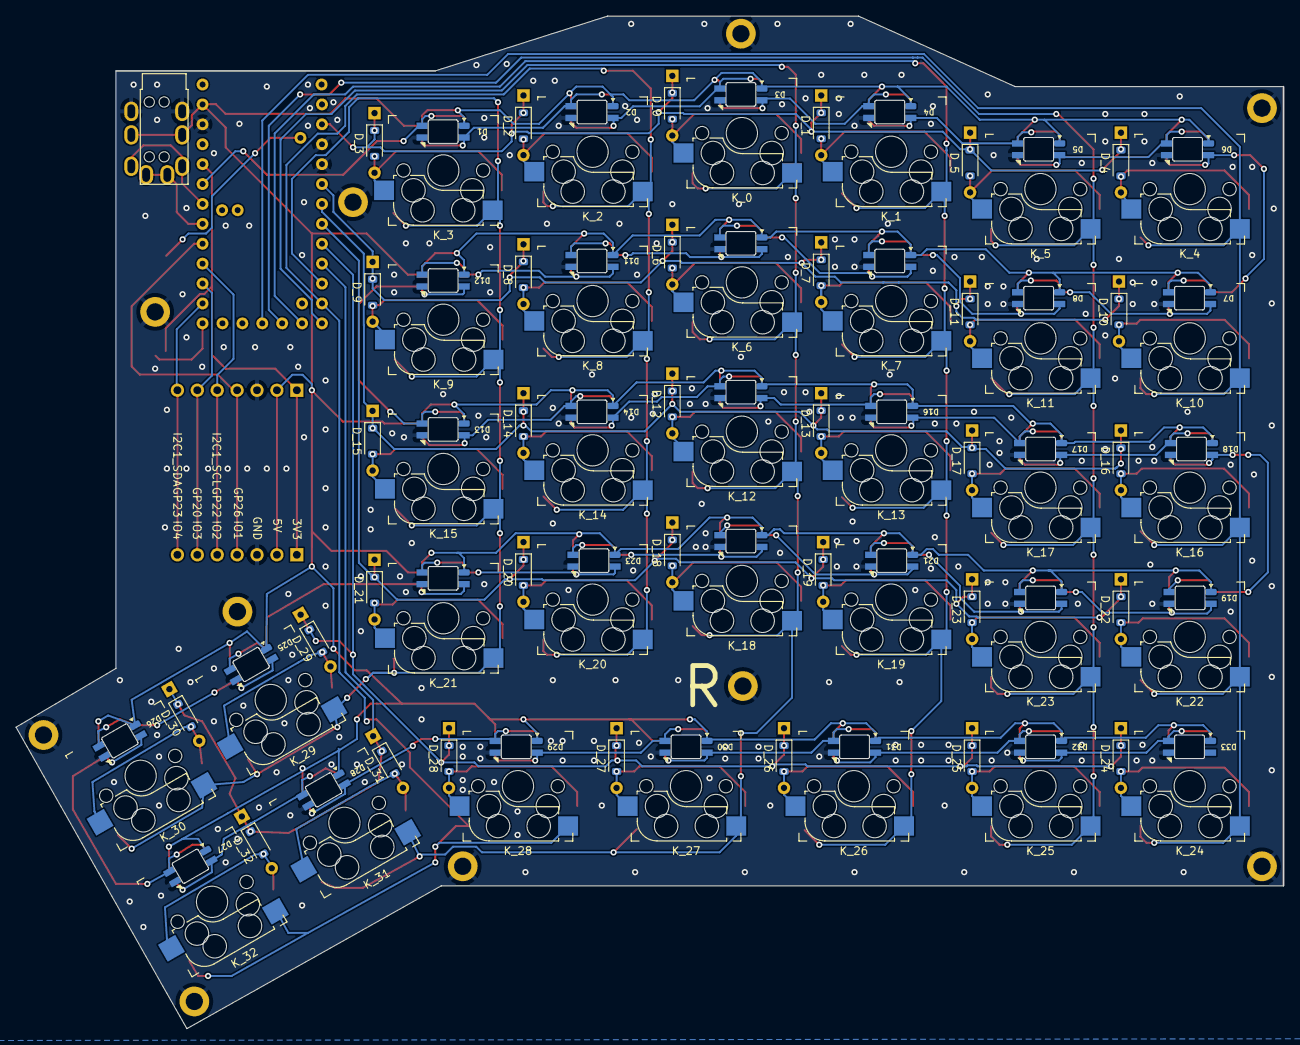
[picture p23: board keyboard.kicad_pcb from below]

Board: 2 copper layers, 161.8 x 129.2 mm, 115 parts (98 on the bottom side), 89 nets.

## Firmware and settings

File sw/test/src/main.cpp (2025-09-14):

#include <FastLED.h>


#define DATA_PIN    29
#define LED_TYPE    SK6812
#define NUM_LEDS    33
CRGB leds[NUM_LEDS];

#define BRIGHTNESS          128
#define FRAMES_PER_SECOND  120

void setup() {
  FastLED.addLeds<LED_TYPE,DATA_PIN>(leds, NUM_LEDS).setCorrection(TypicalLEDStrip);
  FastLED.setBrightness(BRIGHTNESS);
}
   

uint8_t gHue = 0;
           
void loop()
{
  fill_rainbow( leds, NUM_LEDS, gHue, 7);

  FastLED.show();  
  FastLED.delay(1000/FRAMES_PER_SECOND); 
  EVERY_N_MILLISECONDS( 20 ) { gHue++; }
}

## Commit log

2025-08-10 fix accessory connector
    [keyboard.kicad_pcb, keyboard.kicad_sch]
2025-08-16 pcb fixes
    [keyboard.kicad_pcb, keyboard.kicad_sch, keyboard.step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]
2025-08-21 closer thumbcluster, more layout
    [keyboard.kicad_pcb]
2025-08-22 pcb tweaks
    [keyboard.kicad_pcb, keyboard.kicad_sch]
2025-09-14 missing changes
    [BOM-keyboard.csv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]
2025-09-29 added boot hole
    [splitBase.stl]
2026-02-09 fix bom and layout
